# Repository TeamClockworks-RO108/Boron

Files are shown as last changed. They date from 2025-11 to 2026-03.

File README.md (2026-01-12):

# Boron

   

Boron is a DYI light cube for branding purposes, inspired by Voron printer frame construction.

Boron (Box-Voron) is an open-source light cube that can be built for relatively cheap. The sides graphics are interchangeable and allow for quick reconfiguration by unscrewing the top of the frame. It allows us to display a large logo on a structure very similar to Voron printers.

The project is licensed under [GNU General Public License Version 3](https://www.gnu.org/licenses/gpl-3.0.en.html). This means, among others, that distributing either STL, printed parts or assemblies containing Boron, you must also make the modified CAD available to users. 

The design is built so that minimal electronics and soldering work is required. A 10-meter LED strip is cut into 4 equal sections and is wrapped around the cube's guide channels. Each strip's end arrives at the top of the cube, where it transitions to the top face. The electronics operate at 24V to allow the Shelly controller to switch more power for the same current.

A complete build guide, including sourcing tips and step-by-step construction manual can be found on our [wiki page](https://wiki.teamclockworks.ro/en/Projects/boron).

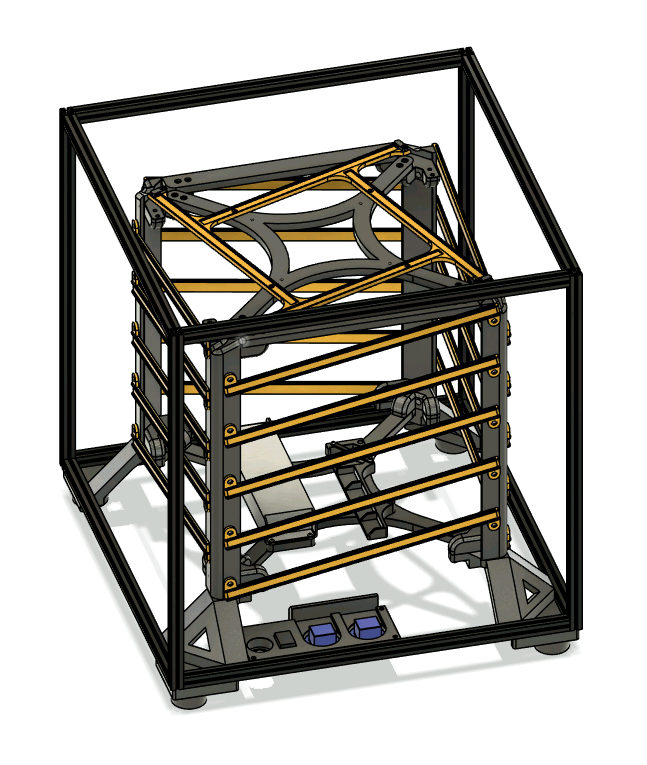
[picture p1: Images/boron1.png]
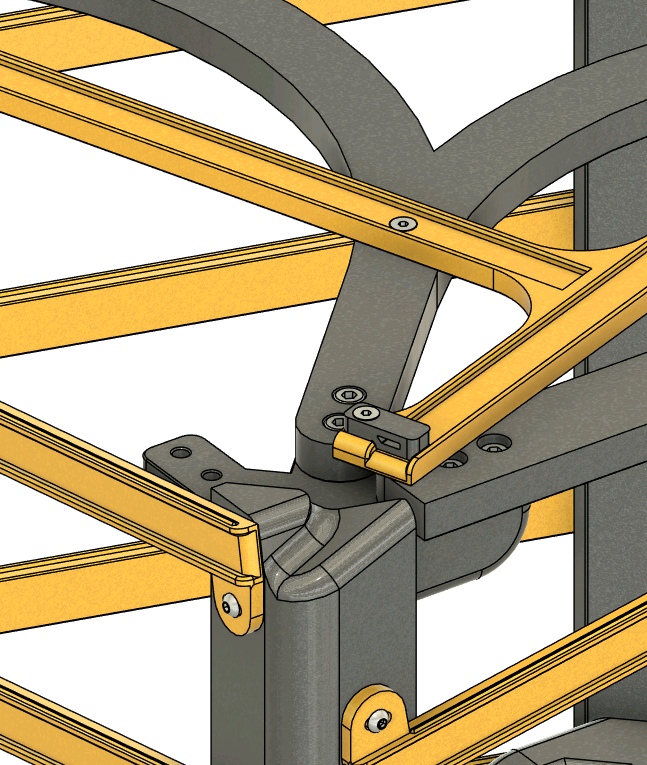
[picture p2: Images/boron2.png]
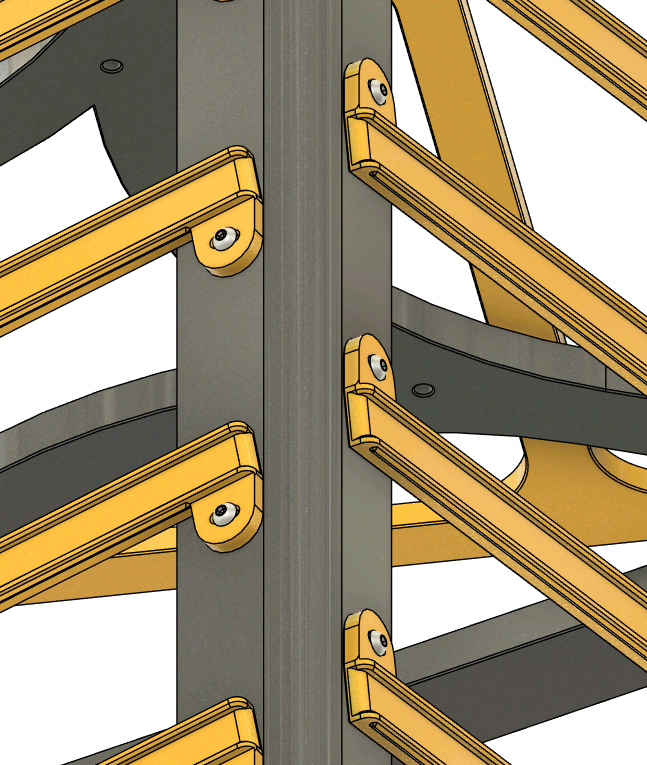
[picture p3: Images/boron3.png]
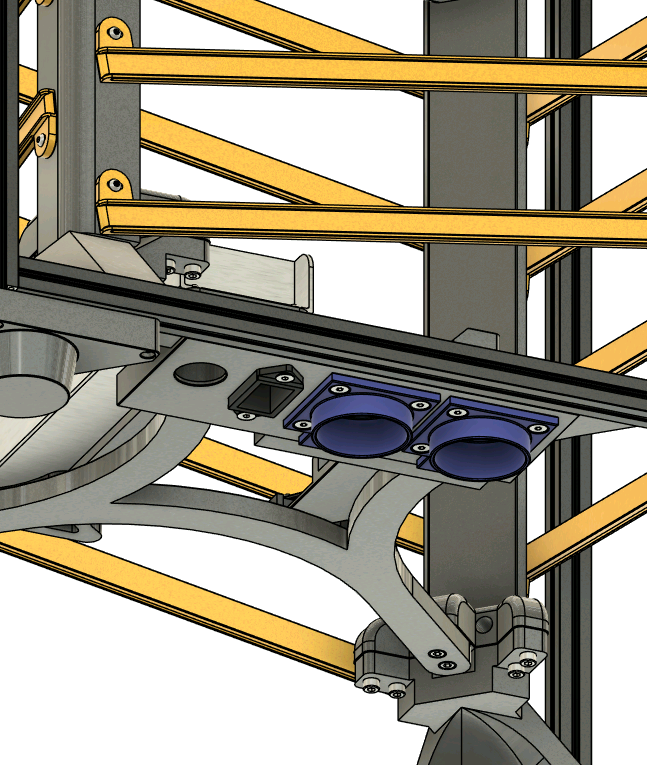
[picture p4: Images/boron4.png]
|  |  |  |  | 
| -- | -- | -- | -- |

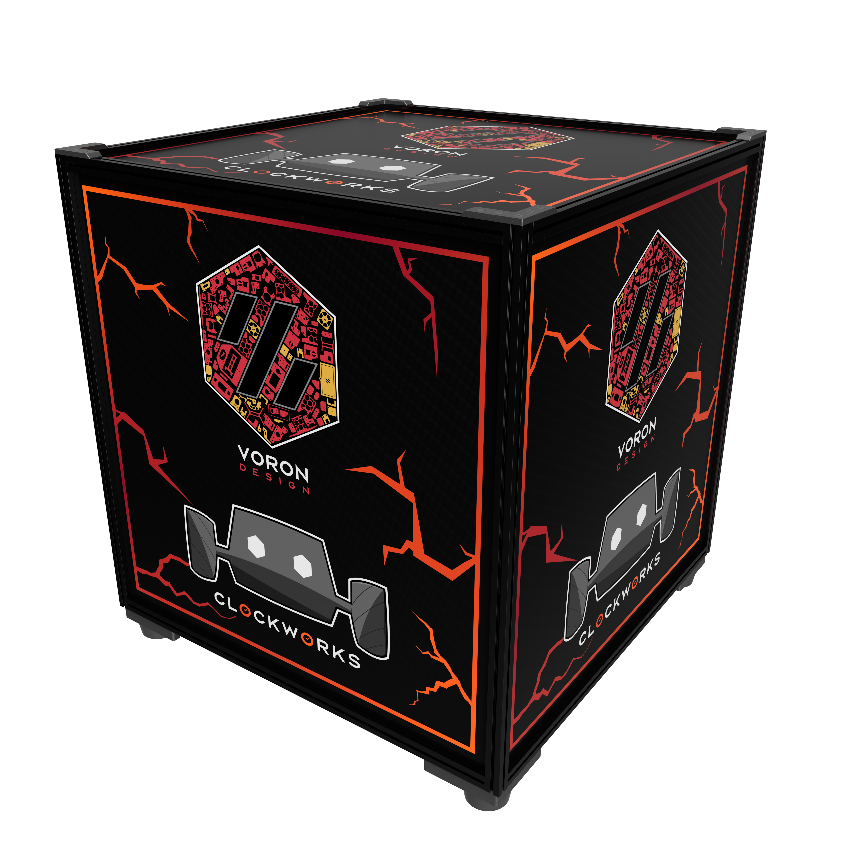
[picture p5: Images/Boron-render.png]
|  |
| -- |

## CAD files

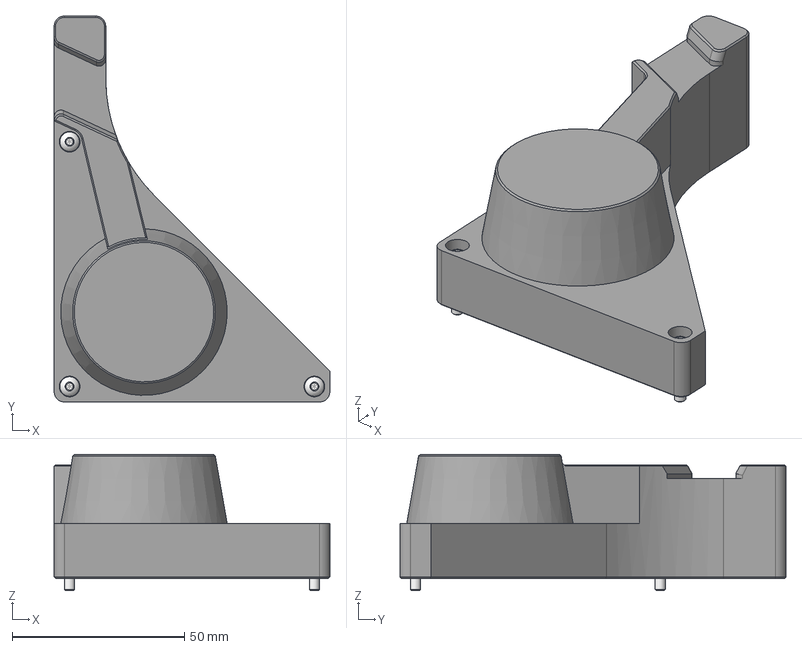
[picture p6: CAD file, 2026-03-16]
CAD/Stacking Foot.step
80.1 x 112.1 x 39.5 mm
DIN EN ISO 7380-1 - M3 x 16 Stainless Steel A2 Plain
DIN EN ISO 7380-1 - M3 x 16 Stainless Steel A2 Plain_1
DIN EN ISO 7380-1 - M3 x 16 Stainless Steel A2 Plain_2

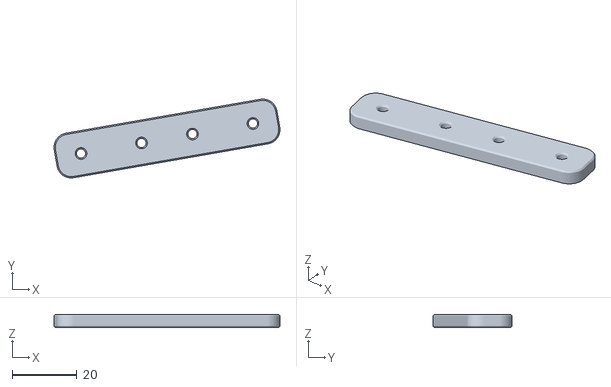
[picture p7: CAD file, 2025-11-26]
STL/modular_channels/CenterChannel.stl
70.0 x 24.4 x 4.00

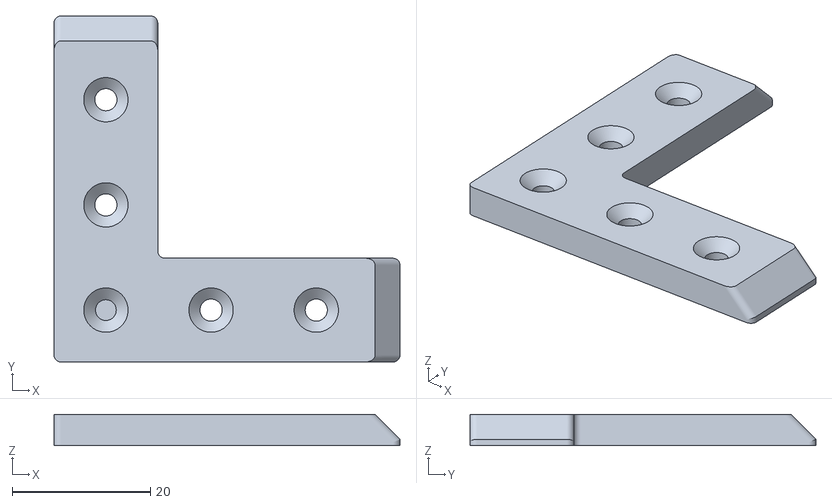
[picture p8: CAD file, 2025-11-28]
STL/TopCorner.stl
50.0 x 50.0 x 4.50

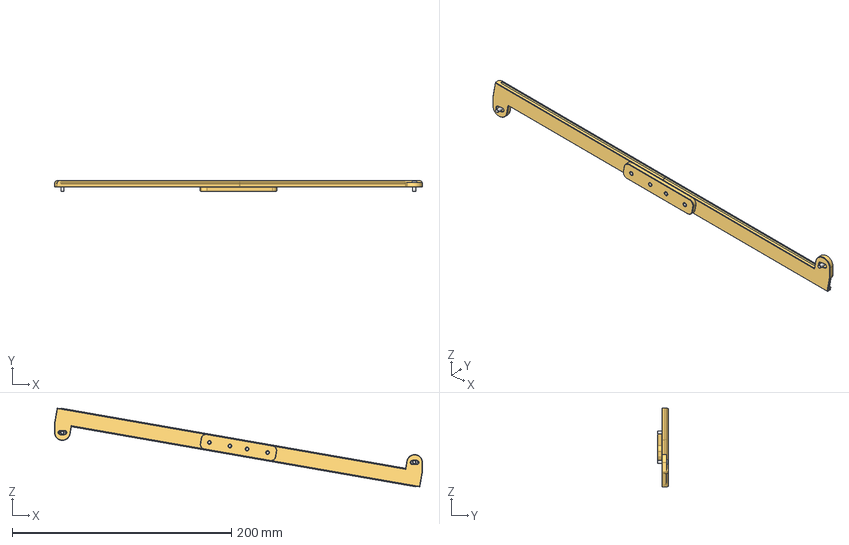
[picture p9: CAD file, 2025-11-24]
CAD/LED Channel Modular.step
336.0 x 10.0 x 72.0 mm
DIN EN ISO 7380-1 - M3 x 8 Stainless Steel A2 Plain x 2
CenterChannel
HalfChannel x 2
DIN 7991 - M3x8 Stainless Steel A2 Plain x 4

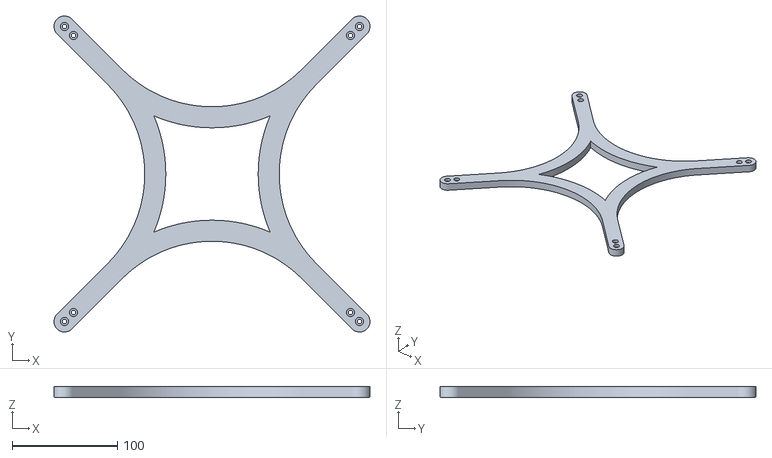
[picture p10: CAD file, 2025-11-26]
STL/BottomCrossbar.stl
299.8 x 299.8 x 10.0

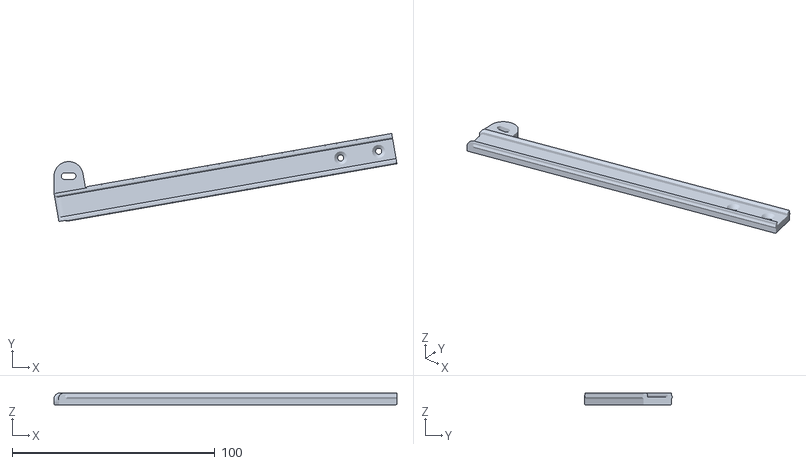
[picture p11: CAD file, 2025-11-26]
STL/modular_channels/HalfChannel.stl
169.2 x 43.4 x 6.00

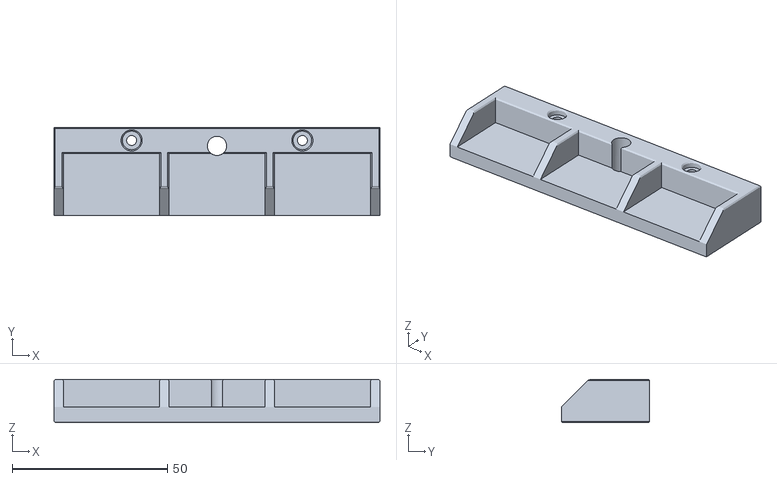
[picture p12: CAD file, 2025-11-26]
STL/WagoHolder.stl
105.0 x 28.5 x 14.0

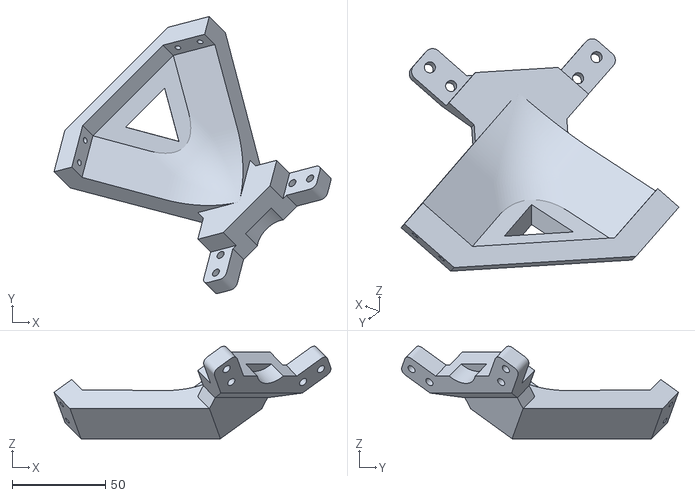
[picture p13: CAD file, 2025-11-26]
STL/InternalFoot.stl
148.1 x 148.1 x 49.5

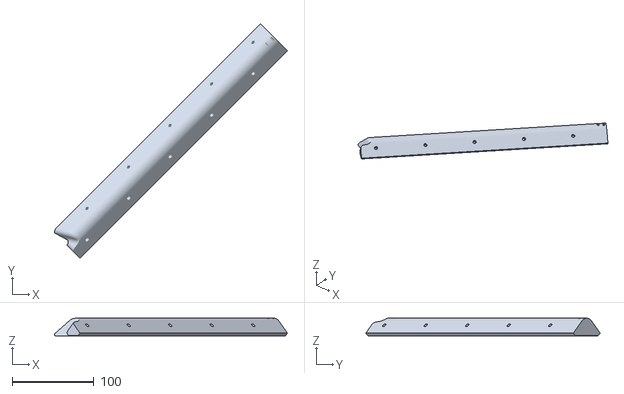
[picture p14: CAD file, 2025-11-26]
STL/Post.stl
285.8 x 287.6 x 21.7

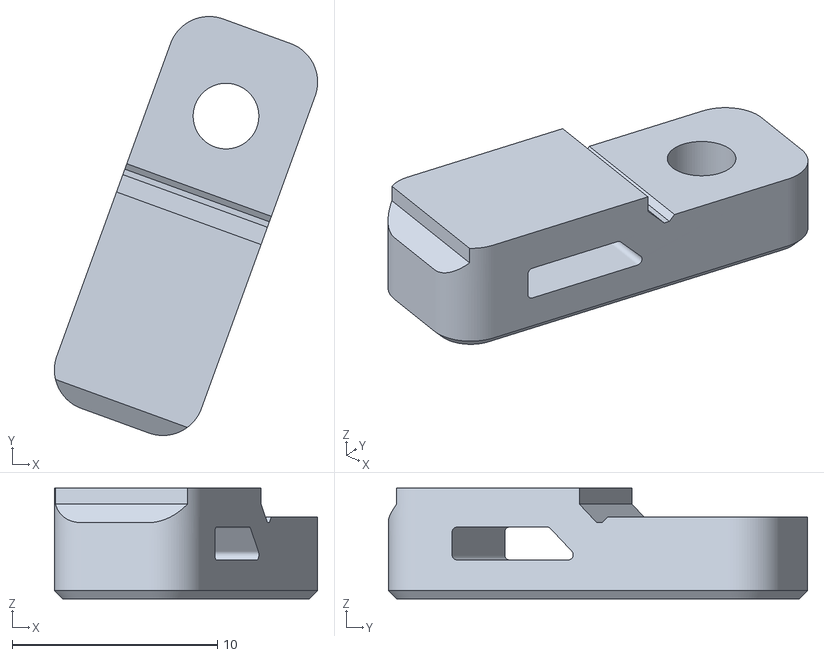
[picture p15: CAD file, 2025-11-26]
STL/StripClip.stl
12.8 x 20.4 x 5.40

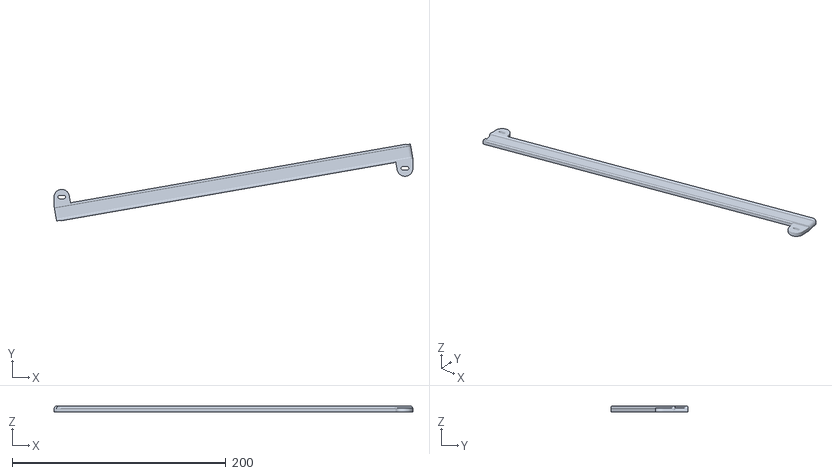
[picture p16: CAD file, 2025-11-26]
STL/LEDChannel.stl
336.0 x 72.0 x 6.00

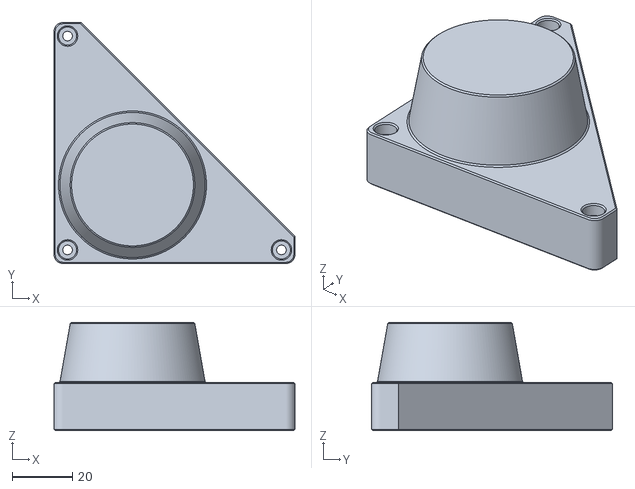
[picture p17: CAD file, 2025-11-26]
STL/Foot.stl
80.1 x 80.1 x 36.0

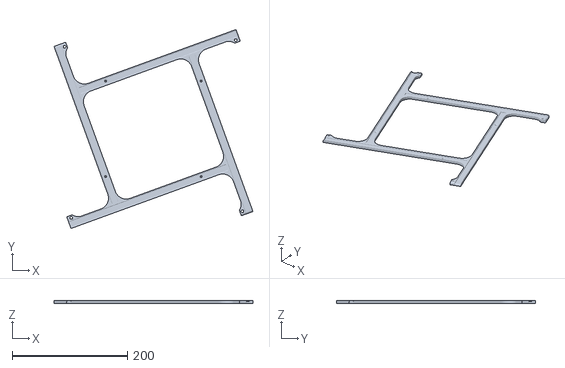
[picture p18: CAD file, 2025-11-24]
STL/LEDChannelTop.stl
344.7 x 344.7 x 6.00

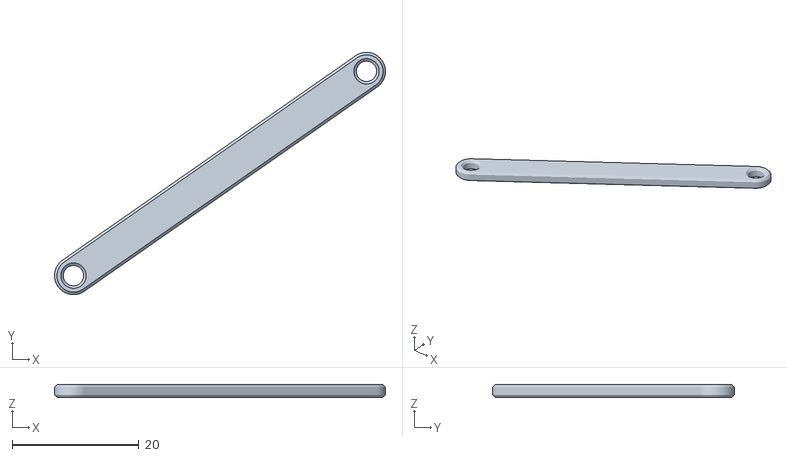
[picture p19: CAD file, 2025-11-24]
STL/ShellyStrap.stl
52.2 x 38.2 x 2.00

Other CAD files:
STL/ShellyBase.stl
STL/Corner.stl
STL/UtilityPanel.stl
STL/TopBar.stl
CAD/LED Channel Modular.f3z
CAD/Stacking Foot.f3d
STL/Stacking Foot.stl
STL/TopCrossbar.stl
STL/UHP-350-Mount.stl

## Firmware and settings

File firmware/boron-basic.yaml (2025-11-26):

esphome:
  name: boron
  friendly_name: boron
  # Restore saved brightness at boot
  on_boot:
    then:
      - light.turn_on:
          id: led_light
          brightness: !lambda 'return id(last_led_brightness);'

esp32:
  variant: esp32
  framework:
    type: esp-idf

logger:
ota:
  platform: esphome

safe_mode:
  disabled: true

api:
  reboot_timeout: 0s

wifi:
  reboot_timeout: 0s
  networks:
  - ssid: !secret wifi1_ssid
    password: !secret wifi1_password
  - ssid: !secret wifi2_ssid
    password: !secret wifi2_password
  - ssid: !secret wifi3_ssid
    password: !secret wifi3_password
  - ssid: !secret wifi4_ssid
    password: !secret wifi4_password

status_led:
  pin: GPIO14

web_server:
  port: 80

globals:
  - id: last_led_brightness
    type: float
    restore_value: true
    initial_value: '0.7' # default for first boot (0.0 - 1.0)

  - id: min_light_pc
    type: float
    initial_value: '0.1'



light:
  - platform: monochromatic
    name: LED
    id: led_light
    output: LED
    default_transition_length: 0s
    gamma_correct: 1.9

output:
  - platform: template
    id: LED
    type: float
    write_action:
      - output.set_level:
          id: LED1
          level: !lambda "return state;"
      - output.set_level:
          id: LED2
          level: !lambda "return state;"
      - output.set_level:
          id: LED3
          level: !lambda "return state;"
      - output.set_level:
          id: LED4
          level: !lambda "return state;"

  - platform: ledc
    pin: GPIO25
    id: LED1
    frequency: 19531

  - platform: ledc
    pin: GPIO26
    id: LED2
    frequency: 19531

  - platform: ledc
    pin: GPIO27
    id: LED3
    frequency: 19531

  - platform: ledc
    pin: GPIO4
    id: LED4
    frequency: 19531

sensor:
  - platform: adc
    pin: GPIO33
    id: temp_analog_reading
    attenuation: 12db

  - platform: resistance
    sensor: temp_analog_reading
    id: temp_resistance_reading
    configuration: DOWNSTREAM
    resistor: 10kOhm

  - platform: ntc
    sensor: temp_resistance_reading
    name: Temperature
    calibration:
      b_constant: 3350
      reference_resistance: 10kOhm
      reference_temperature: 298.15K

  - platform: adc
    pin: GPIO34
    attenuation: 12db
    name: Voltage
    accuracy_decimals: 1
    filters:
      - multiply: 10.85

  - platform: adc
    pin: GPIO35
    attenuation: 12db
    name: Current
    accuracy_decimals: 2
    update_interval: 100ms
    filters:
      - multiply: 16.13
      - offset: -12.53
      - sliding_window_moving_average:
          window_size: 10
          send_every: 10
    unit_of_measurement: A

  - platform: adc
    pin: GPIO36
    name: Potentiometer
    id: potentiometer
    attenuation: 12db
    update_interval: 10ms
    accuracy_decimals: 2
    filters:
      - multiply: 2 # for 10k pullup
      - multiply: 1.23951219512 #  correction
      - multiply: 0.303030 # 1/3.3v to range 0-1
      - sliding_window_moving_average:
          window_size: 20
          send_every: 5
    on_value:
      - lambda: |-
          if (abs(id(last_led_brightness) - x) > 0.01) {
            id(last_led_brightness) = x;
            if (x <= id(min_light_pc)) id(led_light).make_call().set_brightness(id(min_light_pc)).perform();
            else if (x >= 1) id(led_light).make_call().set_brightness(1).perform();
            else id(led_light).make_call().set_brightness(x).perform();
          }

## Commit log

2025-11-24 Add CAD and STL of initial release
    [BottomCrossbar.stl, CenterChannel.stl, Corner.stl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]
2025-11-25 Add LED brightness restoration on boot
    Added global variable for LED brightness restoration and implemented on_boot logic to restore brightness at startup.
2025-11-26 Add missing stl's
    [Foot.stl]
2025-11-26 Reorient parts for print
    [BottomCrossbar.stl, CenterChannel.stl, HalfChannel.stl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]
2025-11-28 Add top corners
    [TopCorner.stl]
2026-02-15 Add stacking foot
    [Stacking Foot.f3d, Stacking Foot.step, Stacking Foot.stl]
2026-03-16 Fix stacking foot depth
    [Stacking Foot.f3d, Stacking Foot.step, Stacking Foot.stl]
